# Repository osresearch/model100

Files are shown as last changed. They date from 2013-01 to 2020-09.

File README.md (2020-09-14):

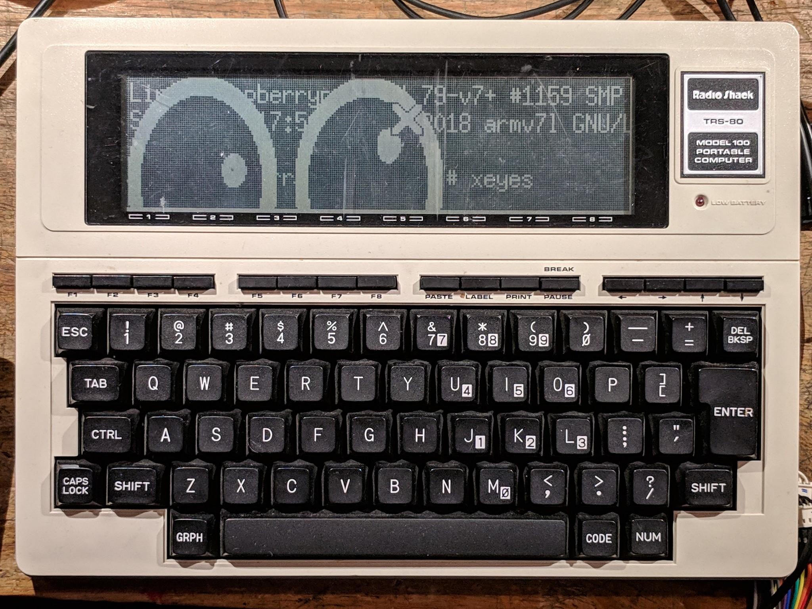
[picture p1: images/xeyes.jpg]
TRS-80 Model 100 "running"


TRS-80 Model iCE100
====

This replaces the mainboard of the TRS-80 Model 100 with an iCE40 FPGA
(or with limited features using a Teensy++) that can act as a serial or
graphics console to a USB attached device.

More info: https://trmm.net/TRS80_Model_100

Pinout
===

The LCD is 240x64 and uses ten Hitachi HD44102 LCD controllers,
each with its own select line and shared control lines.

The LCD requires a charge pump to generate the -5V required for the bias
voltage.  This is generated with a duty cycle controlled PWM output.

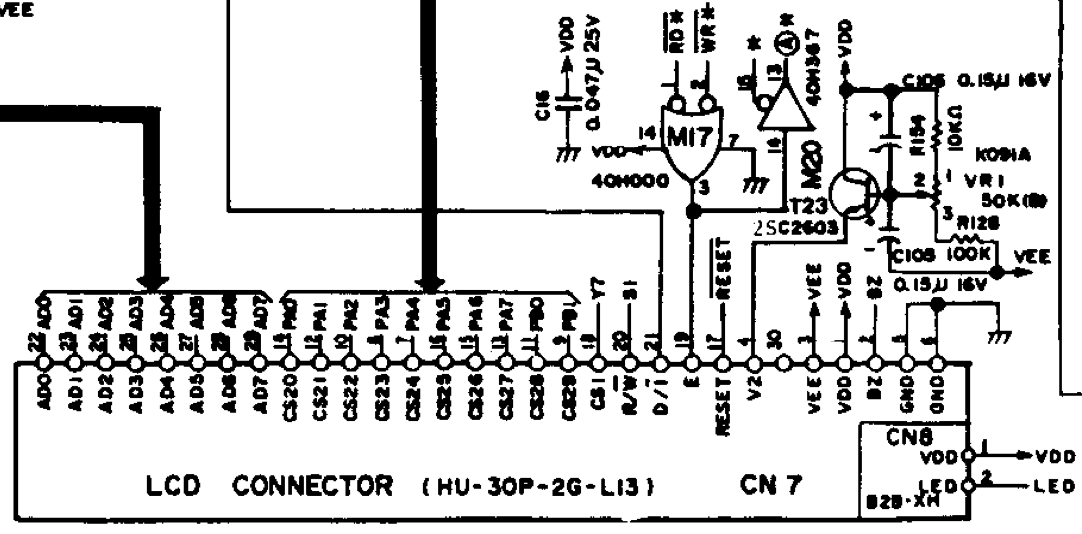
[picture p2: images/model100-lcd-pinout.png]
LCD pinout


LCD connector HU-30P-2G-L13

Pin | Function
----|---------
  1 | VDD
  2 | BZ - buzzer on the front panel (optional)
  3 | VEE -- negative voltage (-5V)
  4 | V2 - contrast voltage (0 - 5V)
  5 | GND
  6 | GND
  7 | CS24
  8 | CS23
  9 | CS29
 10 | CS22
 11 | CS28
 12 | CS21
 13 | CS27
 14 | CS20
 15 | CS26
 16 | CS25
 17 | RESET (can be pulled high for always reset)
 18 | CS1
 19 | E
 20 | R/!W (can be pulled low for always write)
 21 | D/!I
 22 | AD0
 23 | AD1
 24 | AD2
 25 | AD3
 26 | AD4
 27 | AD5
 28 | AD6
 29 | AD7
 30 | NC

LCD bias voltage
===

The LCD requires negative voltage, which is generated with a two diode,
two capacitor charge pump.

           +
    PWM ---||---+--|<--+-- OUT
                |      |
                \/    ---
                --    ---+
                |      |
    GND --------+------+

If it is driven with a 3V signal, the minimum output is around -2 V.
Driving with a 5V PWM produces  -3 V, which gives better contrast.

            5V
             |
             # 100 Ohm
             |
             +-------------- 5V PWM out
             |
             /
    PWM ----|
             \
             v
             |
            GND        

Image format
===
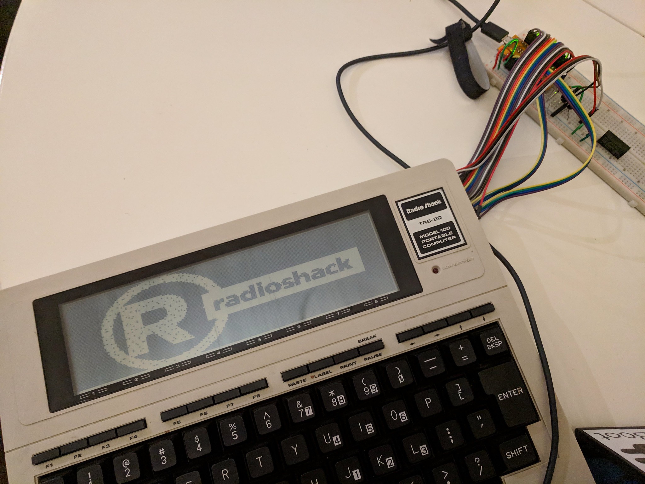
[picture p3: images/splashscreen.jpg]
Splash screen at bootup


    convert -resize !240x64 -depth 1 -monochrome -rotate 90 \
	logo.png logo.gray
    xxd -g8 -c8 -p logo.gray > fb.hex

Keyboard
====

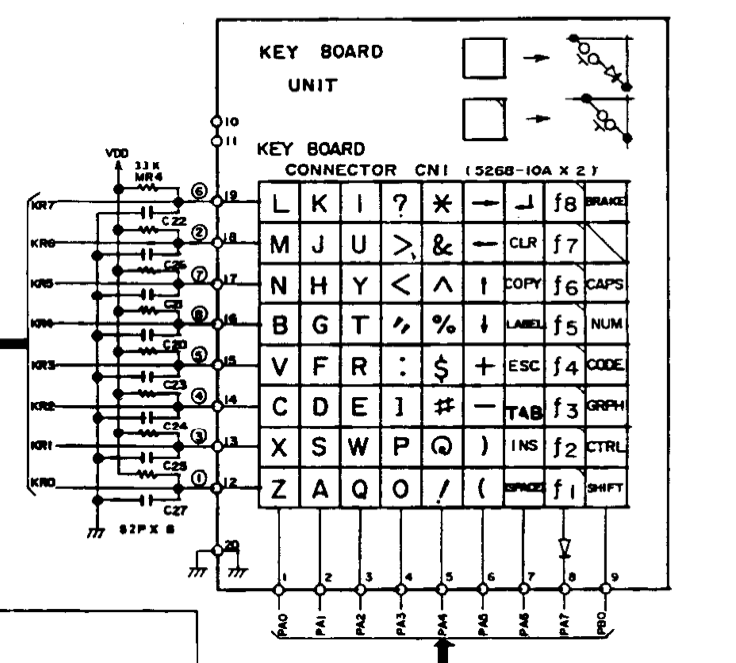
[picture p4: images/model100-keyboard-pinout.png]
Keyboard matrix


The 8x9 keyboard matrix has diodes on every key so it is possible to
identify any number of pressed keys.  However, due to the direction of
the diodes this requires that a slightly odd mechanism be used.

The 8 rows are all configured as input pullups and the 8 of the 9 columns
are driven high.  All the rows are read and any that have been pulled low
due to the diode sinking current to ground are pressed.

          3V
           |
           # internal pullup
           |
    Row ---+---->|--/ --- Col

Upduino v2
===

J6 1.7 5 90
JP6 39.5 1.8 180
JP5 39.5 19.58 180

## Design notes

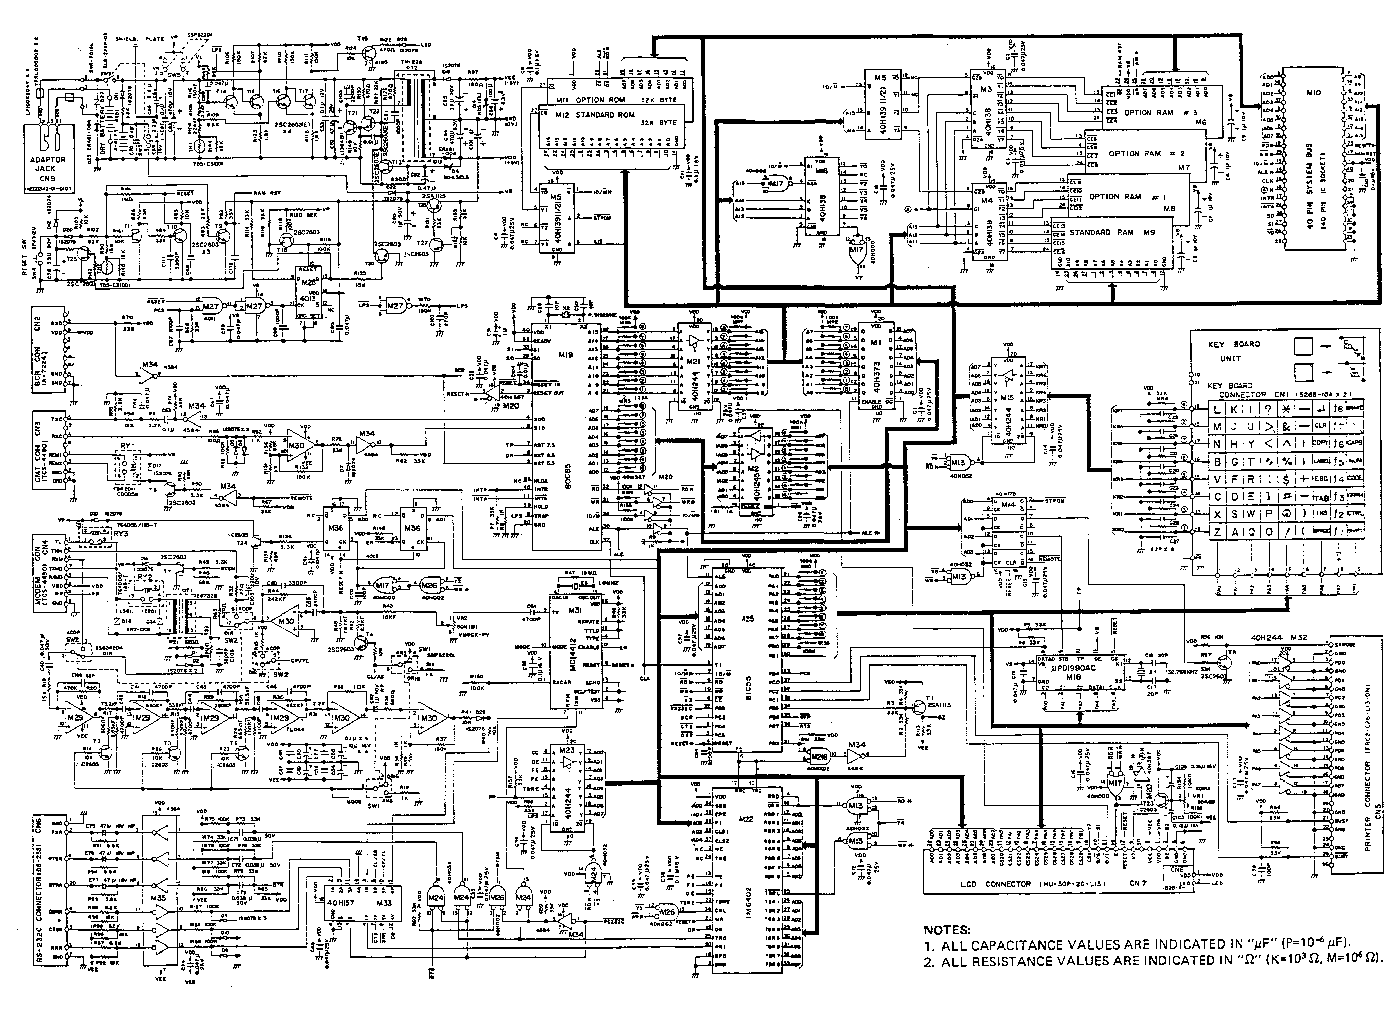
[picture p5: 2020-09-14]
datasheets/model100-schematic.png

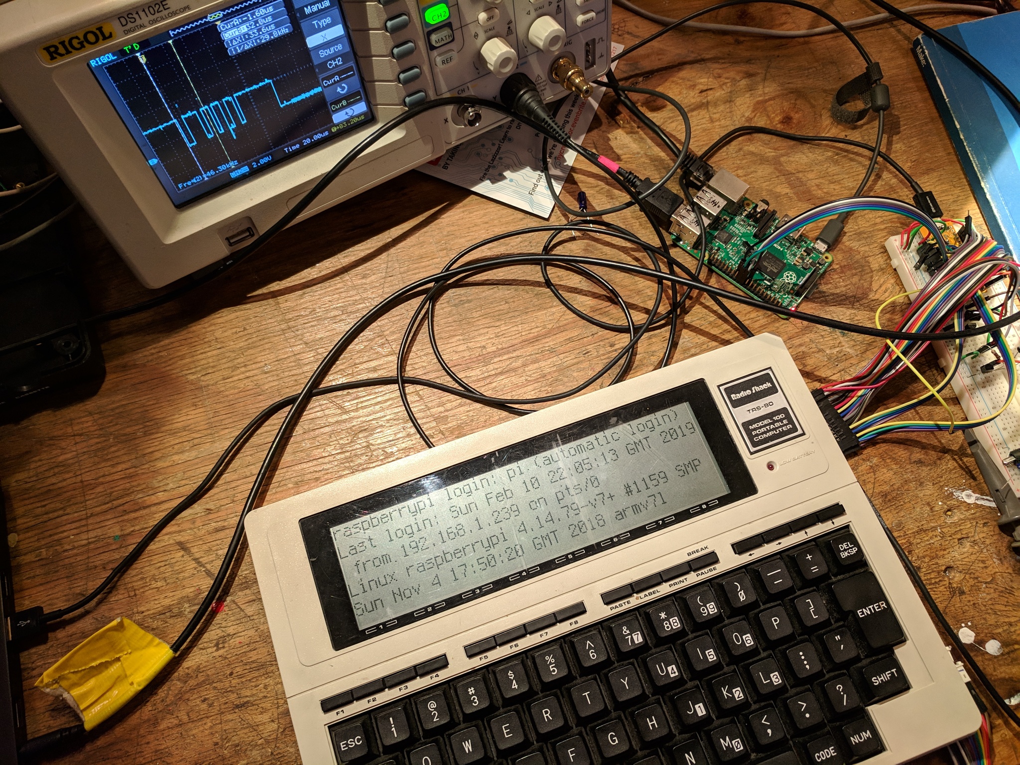
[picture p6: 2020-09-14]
images/timing.jpg

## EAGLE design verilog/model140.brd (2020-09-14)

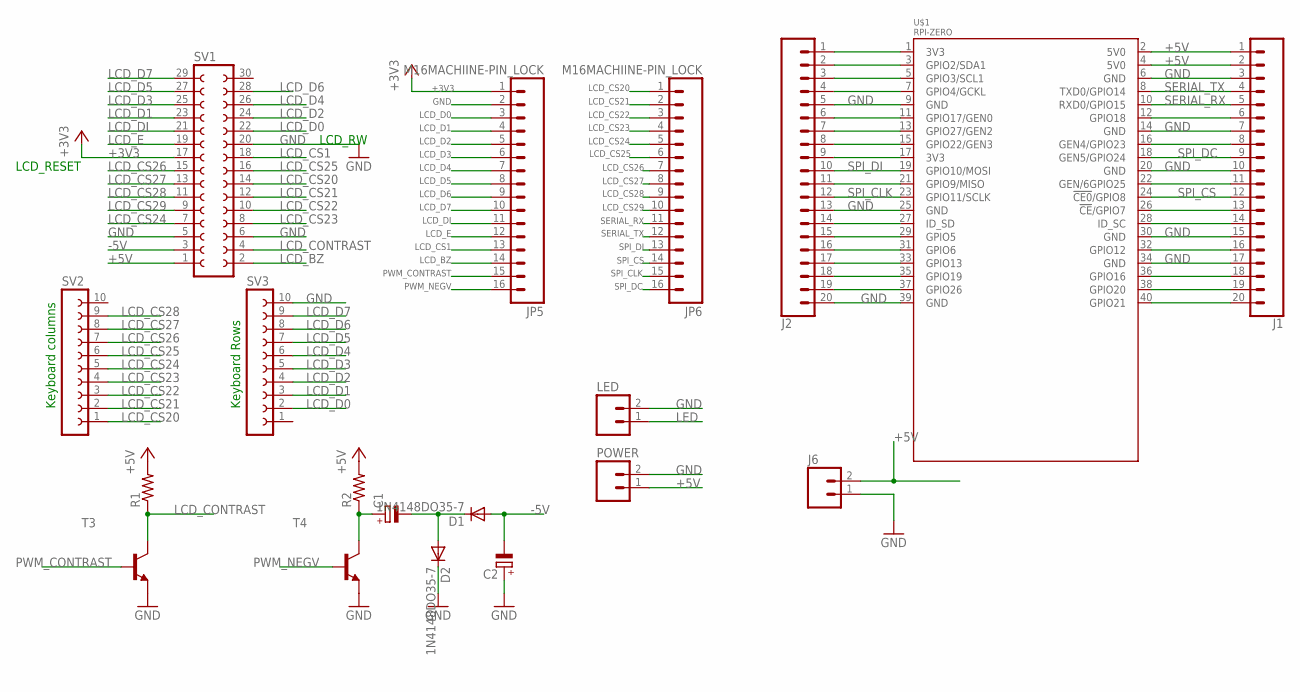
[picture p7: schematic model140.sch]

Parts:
C1, C2: CPOL-EUE2.5-7; E2,5-7
D1, D2: 1N4148DO35-7; DO35-7
J1, J2: CONN_20; 1X20
J6: M02PTH; 1X02
JP5, JP6: M16MACHIINE-PIN_LOCK; 1X16_MACHINE-PIN-HEADER_LOCK.004@1
LED: M02PTH; 1X02
POWER: M02PTH; 1X02
R1, R2: R-US_0204/5; 0204/5
SV1: FE15-2
SV2, SV3: FE10W
T3, T4: MPS2222A-NPN-TO92-CBE; TO92-CBE
U$1: RPI-ZERO; RASP_PI_ZERO_BOARD_FULL

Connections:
3V3@1: J2.1, U$1.1 (3V3)
3V3@2: J2.9, U$1.17 (3V3)
+3V3: JP5.1, SV1.17
+5V: J1.1, J1.2, J6.2, POWER.1, R1.2, R2.2, SV1.1, U$1.2 (5V0), U$1.4 (5V0)
-5V: C2.-, D1.A, SV1.3
GND: C2.+, D2.C, J1.3, J1.7, J1.10, J1.15, J1.17, J2.5, J2.13, J2.20, J6.1, JP5.2, LED.2, POWER.2, SV1.5, SV1.6, SV1.20, SV3.10, T3.E, T4.E, U$1.6 (GND), U$1.9 (GND), U$1.14 (GND), U$1.20 (GND), U$1.25 (GND), U$1.30 (GND), U$1.34 (GND), U$1.39 (GND)
LCD_BZ: JP5.14, SV1.2
LCD_CONTRAST: R1.1, SV1.4, T3.C
LCD_CS1: JP5.13, SV1.18
LCD_CS20: JP6.1, SV1.14, SV2.1
LCD_CS21: JP6.2, SV1.12, SV2.2
LCD_CS22: JP6.3, SV1.10, SV2.3
LCD_CS23: JP6.4, SV1.8, SV2.4
LCD_CS24: JP6.5, SV1.7, SV2.5
LCD_CS25: JP6.6, SV1.16, SV2.6
LCD_CS26: JP6.7, SV1.15, SV2.7
LCD_CS27: JP6.8, SV1.13, SV2.8
LCD_CS28: JP6.9, SV1.11, SV2.9
LCD_CS29: JP6.10, SV1.9
LCD_D0: JP5.3, SV1.22, SV3.2
LCD_D1: JP5.4, SV1.23, SV3.3
LCD_D2: JP5.5, SV1.24, SV3.4
LCD_D3: JP5.6, SV1.25, SV3.5
LCD_D4: JP5.7, SV1.26, SV3.6
LCD_D5: JP5.8, SV1.27, SV3.7
LCD_D6: JP5.9, SV1.28, SV3.8
LCD_D7: JP5.10, SV1.29, SV3.9
LCD_DI: JP5.11, SV1.21
LCD_E: JP5.12, SV1.19
LED: LED.1
unnamed: J2.2, U$1.3 (GPIO2/SDA1)
unnamed: J2.3, U$1.5 (GPIO3/SCL1)
unnamed: J2.4, U$1.7 (GPIO4/GCKL)
unnamed: J2.6, U$1.11 (GPIO17/GEN0)
unnamed: J2.7, U$1.13 (GPIO27/GEN2)
unnamed: J2.8, U$1.15 (GPIO22/GEN3)
unnamed: J2.11, U$1.21 (GPIO9/MISO)
unnamed: J2.14, U$1.27 (ID_SD)
unnamed: J2.15, U$1.29 (GPIO5)
unnamed: J2.16, U$1.31 (GPIO6)
unnamed: J2.17, U$1.33 (GPIO13)
unnamed: J2.18, U$1.35 (GPIO19)
unnamed: J2.19, U$1.37 (GPIO26)
unnamed: J1.20, U$1.40 (GPIO21)
unnamed: J1.19, U$1.38 (GPIO20)
unnamed: J1.18, U$1.36 (GPIO16)
unnamed: J1.16, U$1.32 (GPIO12)
unnamed: J1.14, U$1.28 (ID_SC)
unnamed: J1.13, U$1.26 (!CE!/GPIO7)
unnamed: J1.11, U$1.22 (GEN/6GPIO25)
unnamed: J1.8, U$1.16 (GEN4/GPIO23)
unnamed: J1.6, U$1.12 (GPIO18)
unnamed: C1.+, R2.1, T4.C
unnamed: C1.-, D1.C, D2.A
PWM_CONTRAST: JP5.15, T3.B
PWM_NEGV: JP5.16, T4.B
SERIAL_RX: J1.5, JP6.11, U$1.10 (RXD0/GPIO15)
SERIAL_TX: J1.4, JP6.12, U$1.8 (TXD0/GPIO14)
SPI_CLK: J2.12, JP6.15, U$1.23 (GPIO11/SCLK)
SPI_CS: J1.12, JP6.14, U$1.24 (!CE0!/GPIO8)
SPI_DC: J1.9, JP6.16, U$1.18 (GEN5/GPIO24)
SPI_DI: J2.10, JP6.13, U$1.19 (GPIO10/MOSI)

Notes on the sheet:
Keyboard Rows
Keyboard columns
LCD_RW
LCD_RESET

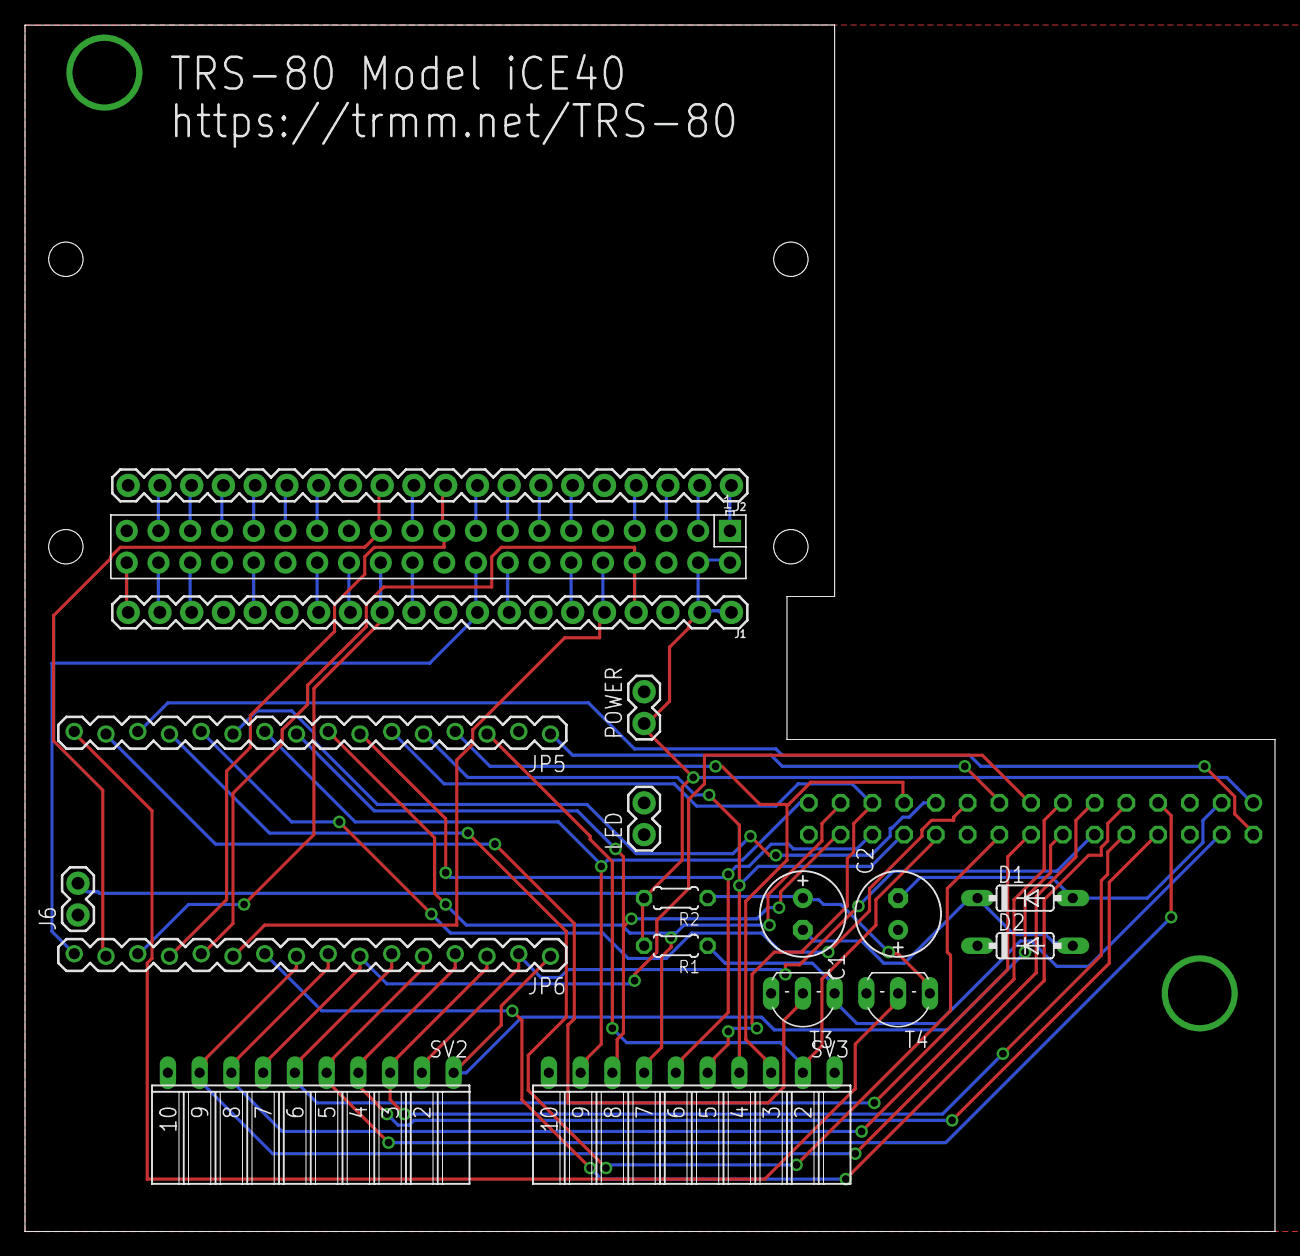
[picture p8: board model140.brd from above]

Board: 2 copper layers, 100.0 x 96.5 mm, 19 parts (1 on the bottom side), 61 nets.

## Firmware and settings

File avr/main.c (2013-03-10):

/**
 * \file Model 100 motherboard.
 */

#include <avr/io.h>
#include <avr/pgmspace.h>
#include <avr/interrupt.h>
#include <avr/eeprom.h>
#include <stdint.h>
#include <string.h>
#include <util/delay.h>
#include "usb_serial.h"
#include "bits.h"
#include "vt100.h"
#include "lcd.h"
#include "font.h"
#include "keyboard.h"


#define LED		0xD6

void send_str(const char *s);
uint8_t recv_str(char *buf, uint8_t size);
void parse_and_execute_command(const char *buf, uint8_t num);

static inline uint8_t
hexdigit(
	uint8_t x
)
{
	x &= 0xF;
	if (x < 0xA)
		return x + '0' - 0x0;
	else
		return x + 'A' - 0xA;
}



// Send a string to the USB serial port.  The string must be in
// flash memory, using PSTR
//
void send_str(const char *s)
{
	char c;
	while (1) {
		c = pgm_read_byte(s++);
		if (!c) break;
		usb_serial_putchar(c);
	}
}


static void
fill_screen(void)
{
	static uint8_t val;

#if 1
	for (uint8_t j = 0 ; j < 8 ; j++)
	{
		for (uint8_t i = 0 ; i < 40 ; i++)
		{
			val = (val + 1) & 0x3F;
			font_draw(i, j, val + '0', FONT_NORMAL);
		}
	}
#else
	for (uint8_t y = 0 ; y < 64 ; y += 8)
	{
		for (uint8_t x = 0 ; x < 240 ; x++)
		{
			lcd_display(x, y, val++);
		}
	}
#endif

	val++;
}


static void
key_special(
	const uint8_t key
)
{
	if (key == 0x81)
	{
		// f1 == redraw everything
		vt100_clear();
		vt100_goto(0, 0);
		return;
	}

	if (0x90 <= key && key <= 0x93)
	{
		uint8_t buf[2];
		buf[0] = '\e';
		buf[1] = 'A' + key - 0x90;
		usb_serial_write(buf, 2);
		return;
	}
}



/** Hardware serial port interrupt handler */
#define RX_QUEUE_SIZE 128
static volatile uint8_t rx_head; // where the next will be written
static volatile uint8_t rx_tail; // where the next will be read
static uint8_t rx_buf[RX_QUEUE_SIZE];

ISR(USART1_RX_vect)
{ 
	char c = UDR1;
	if (rx_head == rx_tail + RX_QUEUE_SIZE)
		return;
	rx_buf[rx_head++ % RX_QUEUE_SIZE] = c;
}


int
serial_getchar(void)
{
	uint8_t tail = rx_tail;
	if (rx_head == tail)
		return -1;
	char c = rx_buf[tail % RX_QUEUE_SIZE];
	rx_tail = tail + 1;
	return c;
}


int
main(void)
{
	// set for 16 MHz clock
#define CPU_PRESCALE(n) (CLKPR = 0x80, CLKPR = (n))
	CPU_PRESCALE(0);

	// Disable the ADC
	ADMUX = 0;

#ifdef CONFIG_USB_SERIAL
	// initialize the USB, and then wait for the host
	// to set configuration.  If the Teensy is powered
	// without a PC connected to the USB port, this 
	// will wait forever.
	usb_init();
#else
	// We're not using USB, so setup the normal serial port
	// 115.2k, n81, no interrupts
	UBRR1 = 8; // 115.2k
	UCSR1B = (1 << RXEN1) | (1 << TXEN1) | (1 << RXCIE1);
	UCSR1C = (0 << USBS1) | (3 << UCSZ10);
	sei();
#endif

	// LED is an output; will be pulled down once connected
	ddr(LED, 1);
	out(LED, 1);

	lcd_init();

        // Timer 0 is used for a 64 Hz control loop timer.
        // Clk/256 == 62.5 KHz, count up to 125 == 500 Hz
        // Clk/1024 == 15.625 KHz, count up to 125 == 125 Hz
        // CTC mode resets the counter when it hits the top
        TCCR0A = 0
                | 1 << WGM01 // select CTC
                | 0 << WGM00
                ;

        TCCR0B = 0
                | 0 << WGM02
                | 1 << CS02 // select Clk/256
                | 0 << CS01
                | 1 << CS00
                ;

        OCR0A = 125;
        sbi(TIFR0, OCF0A); // reset the overflow bit

#ifdef CONFIG_USB_SERIAL
	while (!usb_configured())
		;

	_delay_ms(1000);

	// wait for the user to run their terminal emulator program
	// which sets DTR to indicate it is ready to receive.
	while (!(usb_serial_get_control() & USB_SERIAL_DTR))
		;

	// discard anything that was received prior.  Sometimes the
	// operating system or other software will send a modem
	// "AT command", which can still be buffered.
	usb_serial_flush_input();

	send_str(PSTR("lcd model100\r\n"));
#endif

	fill_screen();

	uint8_t last_key = 0;

	while (1)
	{
#ifdef CONFIG_USB_SERIAL
		int c = usb_serial_getchar();
#else
		int c = serial_getchar();
#endif
		if (c != -1)
		{
			vt100_putc(c);
		}

		uint8_t key = keyboard_scan();
		if (key == 0)
		{
			last_key = 0;
		} else
		if (key != last_key)
		{
			last_key = key;
			if (key >= 0x80)
			{
				// Special char!
				key_special(key);
			} else {
#ifdef CONFIG_USB_SERIAL
				// Normal, send it USB
				usb_serial_putchar(key);
#else
				// Normal, send it serial
				while (bit_is_clear(UCSR1A, UDRE1))
					;
				UDR1 = key;
#endif
			}
		}

		if (bit_is_clear(TIFR0, OCF0A))
			continue;

		sbi(TIFR0, OCF0A); // reset the bit
	}
}

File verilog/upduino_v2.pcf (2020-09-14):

# The LED pins are using the current controlled outputs
# and are negative logic (write a 0 to turn on).
set_io -nowarn led_r	41
set_io -nowarn led_g	39
set_io -nowarn led_b	40

# FTDI chip, which sort of works
set_io -nowarn serial_txd 14 # FPGA transmit to USB
set_io -nowarn serial_rxd 15 # FPGA receive from USB
set_io -nowarn spi_flash_cs 16 # Drive high to ensure that the SPI flash is disabled
# set_io serial_rts_n 14  # no?
# set_io serial_dtr_n 16  # no?

# Normal GPIO pins, left side
set_io -nowarn gpio_23 23
set_io -nowarn gpio_25 25
set_io -nowarn gpio_26 26
set_io -nowarn gpio_27 27
set_io -nowarn gpio_32 32
set_io -nowarn gpio_35 35
set_io -nowarn gpio_31 31
set_io -nowarn gpio_37 37
set_io -nowarn gpio_34 34
set_io -nowarn gpio_43 43
set_io -nowarn gpio_36 36
set_io -nowarn gpio_42 42
set_io -nowarn gpio_38 38
set_io -nowarn gpio_28 28

# Normal GPIO pins, right side
set_io -nowarn gpio_12 12
set_io -nowarn gpio_21 21
set_io -nowarn gpio_13 13
set_io -nowarn gpio_19 19
set_io -nowarn gpio_18 18
set_io -nowarn gpio_11 11
set_io -nowarn gpio_9 9
set_io -nowarn gpio_6 6
set_io -nowarn gpio_44 44
set_io -nowarn gpio_4 4
set_io -nowarn gpio_3 3
set_io -nowarn gpio_48 48
set_io -nowarn gpio_45 45
set_io -nowarn gpio_47 47
set_io -nowarn gpio_46 46
set_io -nowarn gpio_2 2

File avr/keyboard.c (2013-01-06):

/**
 * \file Model 100 keyboard matrix reader
 *
 * Keyboard needs:
 *	9 columns, shared with the 10 LCD chipselect lines
 *	8 rows, must not be shared.
 */

#include <avr/io.h>
#include <avr/pgmspace.h>
#include <avr/interrupt.h>
#include <avr/eeprom.h>
#include <stdint.h>
#include <string.h>
#include <util/delay.h>
#include "usb_serial.h"
#include "bits.h"
#include "keyboard.h"

// Can not be shared with the LCD
#define KEY_ROWS_PIN	PINA
#define KEY_ROWS_DDR	DDRA
#define KEY_ROWS_PORT	PORTA

// Shared with LCD chip select lines
#define KEY_COLS_PIN	PINF
#define KEY_COLS_DDR	DDRF
#define KEY_COLS_PORT	PORTF
#define KEY_COLS_MOD	0xE6 // shared with LCD_CS8

// The bits on the modifier column
#define KEY_MOD_SHIFT	0x01
#define KEY_MOD_CONTROL	0x02
#define KEY_MOD_GRAPH	0x04
#define KEY_MOD_CODE 	0x08
#define KEY_MOD_NUMLOCK	0x10
#define KEY_MOD_CAPS	0x20
#define KEY_MOD_NC	0x40
#define KEY_MOD_BREAK	0x80


/** Layout of the rows and columns in normal mode */
static const uint8_t key_codes[8][8] PROGMEM =
{
	[0] = "\x81\x82\x83\x84\x85\x86\x87\x88", // function keys
	[1] = "zxcvbnml",
	[2] = "asdfghjk",
	[3] = "qwertyui",
	[4] = "op[;',./",
	[5] = "12345678",
	[6] = "90-=\x92\x93\x90\x91", // need to handle arrows
	[7] = " \x8\t\eLC0\n", // need to handle weird keys
};


/** Layout of the rows and columns when shifted */
static const uint8_t shift_codes[8][8] PROGMEM =
{
	[0] = "\x81\x82\x83\x84\x85\x86\x87\x88", // function keys
	[1] = "ZXCVBNML",
	[2] = "ASDFGHJK",
	[3] = "QWERTYUI",
	[4] = "OP]:\"<>?",
	[5] = "!@#$%^&*",
	[6] = "()_+\x92\x93\x90\x91", // need to handle arrows
	[7] = " \x8\t\eLC0\n", // need to handle weird keys
};


/** Initialize the keyboard for a scan.
 *
 * This is called before each read of the keyboard, unlike the
 * LCD that is initialized at boot time.
 */
static void
keyboard_init(void)
{
	// KEY_Cx configuration is handled in lcd_init() sincej
	// they are shared with the chip select lines of the LCD 
	KEY_ROWS_DDR = 0x00; // all input
	KEY_ROWS_PORT = 0xFF; // all pull ups enabled

	KEY_COLS_DDR = 0xFF; // all output
	KEY_COLS_PORT = 0xFF; // all high

	// Pull the function key line high, too
	ddr(KEY_COLS_MOD, 1);
	out(KEY_COLS_MOD, 1);
}


/** Return the keyboard to the normal state (LCD writing).
 *
 */
static void
keyboard_reset(void)
{
	KEY_ROWS_DDR = 0x00; // all inputs
	KEY_ROWS_PORT = 0x00; // all tri-state

	KEY_COLS_DDR = 0xFF; // leave as all output
	KEY_COLS_PORT = 0x00; // all low

	// Reset the function key modifier to pull down, too
	ddr(KEY_COLS_MOD, 1);
	out(KEY_COLS_MOD, 0);
}



static uint8_t
keyboard_scancode_convert(
	uint8_t col,
	uint8_t rows,
	uint8_t mods
)
{
	for (uint8_t row = 0, mask = 1 ; row < 8 ; row++, mask <<= 1)
	{
		if ((rows & mask) == 0)
			continue;

		char c = pgm_read_byte(&(
			(mods & KEY_MOD_SHIFT) && !(mods & KEY_MOD_CONTROL)
			? shift_codes
			: key_codes
		)[col][row]);

		// If control is held, only allow a-z
		// Send nothing, otherwise
		if (mods & KEY_MOD_CONTROL)
		{
			if ('a' <= c && c <= 'z')
				return 0x1 + c - 'a';
			return 0;
		}

		// If we are caps locked, switch lower and upper
		if (mods & KEY_MOD_CAPS)
		{
			if ('a' <= c && c <= 'z')
				c -= 32;
			else
			if ('A' <= c && c <= 'Z')
				c += 32;
		}

		return c;
	}

	// Scan code converts to nothing...
	return 0;
}


/** Check to see if there are any keys held down.
 *
 * \todo Scans only one column per call?
 *
 * \todo Multiple keys held?
 *
 * \return 0 if no keys are held down
 */
uint8_t
keyboard_scan(void)
{
	keyboard_init();


	// Scan the modifier column first, which is on the separate pin
	out(KEY_COLS_MOD, 0);
	_delay_us(50);
	const uint8_t mods = ~KEY_ROWS_PIN;
	out(KEY_COLS_MOD, 1);

	uint8_t mask = 1;
	for (uint8_t col = 0 ; col < 8 ; col++, mask <<= 1)
	{
		KEY_COLS_PORT = ~mask; // pull one down
		_delay_us(50); // wait for things to stabilize
		uint8_t rows = ~KEY_ROWS_PIN;
		KEY_COLS_PORT = 0xFF; // bring them all back up

		if (!rows)
			continue;

		keyboard_reset();

		return keyboard_scancode_convert(col, rows, mods);
	}

	keyboard_reset();
	return 0;
}

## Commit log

2012-11-22 4-bit LCD driver works
2012-12-01 driver works, contrast sucks
2013-03-10 Serial talks to the raspberry pi! need to add scrolling
2013-03-10 Correct sense of UDRE1 -- serial console works!
    [main.c]
2019-02-02 negative voltage output works
2019-02-02 lcd driver, not working yet
    [upduino_v2.pcf]
2019-02-02 fix sense of pwm
2019-02-03 fix sense of enable pin, do not try to select all modules at the same time
2019-02-03 correct pinout on cable
2019-02-03 correct dimension and cs pin switch at end of line
2019-02-04 started on "model140" interface board and analog components
    [model140.sch]
2019-02-05 preparing for keyboard wiring
2019-02-06 lcd frame strobe to coordinate access to lcd data pins with keyboard
2019-02-07 pi zero-w version with upduino v2
    [model140.brd, model140.sch]
2019-02-07 add pi-zero header duplicate
    [model140.brd, model140.sch]
2019-02-10 as ordered
    [model140.brd]
2019-02-10 working on spi display interface
2019-02-10 spi display almost works!
2019-02-10 spi display device works!
2019-02-16 works with the model140 board
2020-09-14 move verilog code into subdir
    [model140.brd, model140.sch]
2020-09-14 note that this is both teensy and verilog code now

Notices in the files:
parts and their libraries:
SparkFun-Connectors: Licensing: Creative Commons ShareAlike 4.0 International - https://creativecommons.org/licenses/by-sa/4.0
